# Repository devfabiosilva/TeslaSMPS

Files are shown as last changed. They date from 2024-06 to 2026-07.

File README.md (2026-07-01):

# TeslaSMPS

DIY: High Voltage Range Switching Mode Power Supply for Embedded / Solar and industrial systems

## 2026 KiCad Design Contest

Sponsored by PCB Way. See details [here](https://www.pcbway.com/project/shareproject/TeslaSMPS_Simple_3_Transistor_Ultra_Wide_Range_100V_820V_AC_142V_1160V_DC_c3cf9745.html)

<p align="center">
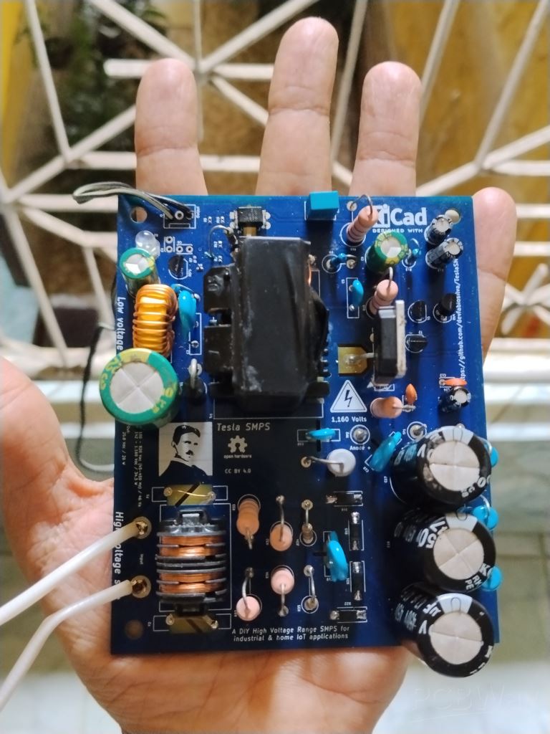
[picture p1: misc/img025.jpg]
  
</p>

<p align="center">
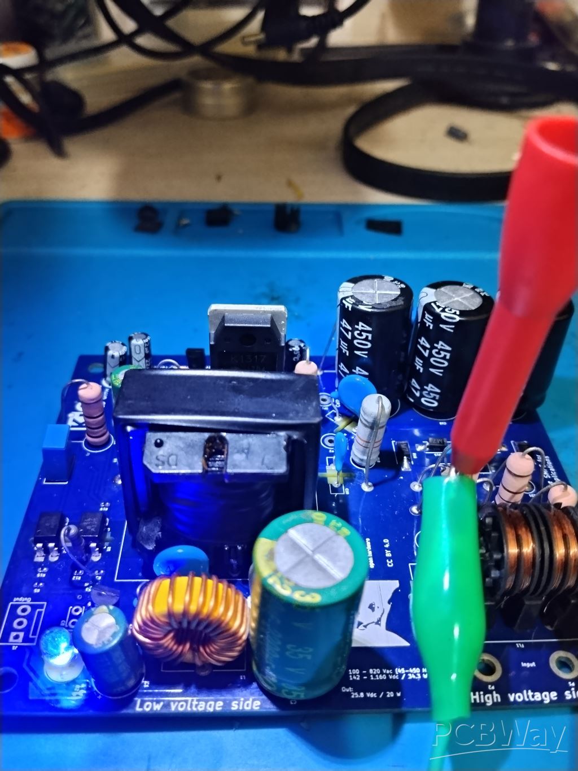
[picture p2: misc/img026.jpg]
  
</p>

### Old handmade version 2015

<p align="center">
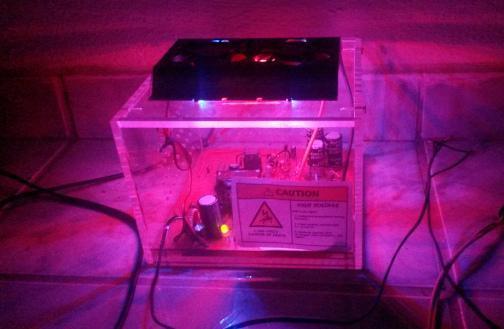
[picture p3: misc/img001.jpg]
  
</p>

## Brief description

This is a DIY WVR-SMPS (Wide Voltage Range Switching Mode Power Supply) or simply Tesla SMPS is a wide range and high voltage input for low power embedded systems. This device allows input voltage as low as 100 VAC and as high as 820 VAC in wide frequency range (45 − 450 Hz) or even in DC voltage as low as 142 VDC and as high as 1,160 VDC using only 3 transistors

[State of the art](https://github.com/devfabiosilva/TeslaSMPS/blob/master/01-concept/StateOfTheArt.pdf)

## Basic Block diagram

<p align="center">
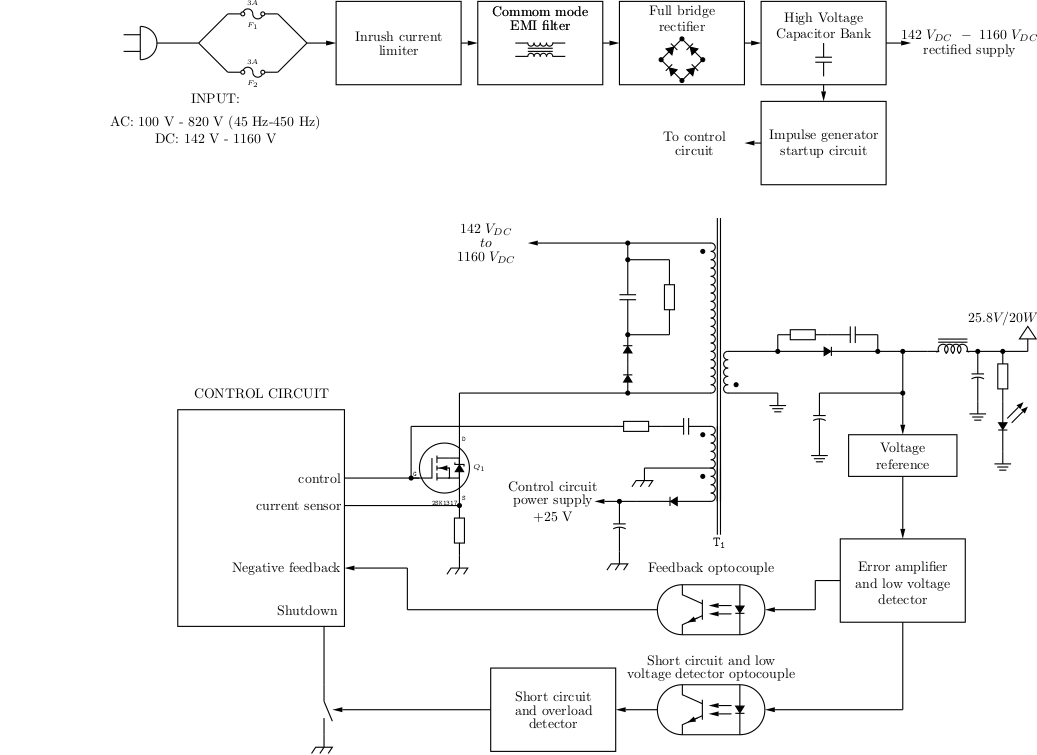
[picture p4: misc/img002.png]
  
</p>

## PCB Version

<p align="center">
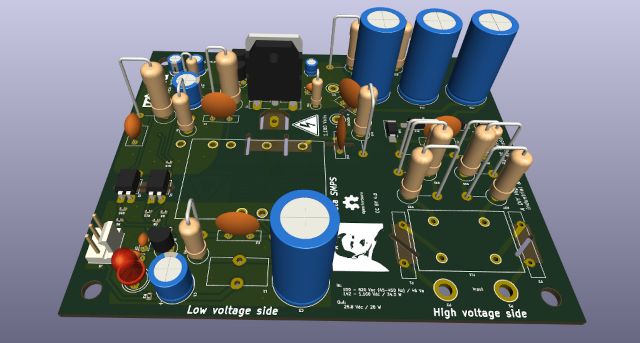
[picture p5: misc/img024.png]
  
</p>

<p align="center">
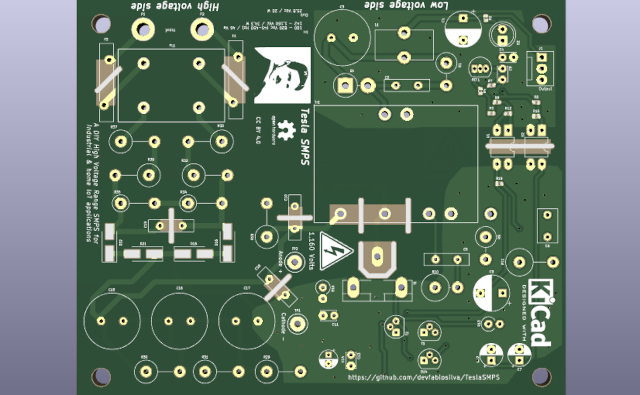
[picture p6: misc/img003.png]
  
</p>

You can find PCB version in:

- [Gerber files](https://github.com/devfabiosilva/TeslaSMPS/tree/master/02-schematic_and_gerber_files/gerber)

- [Source code](https://github.com/devfabiosilva/TeslaSMPS/tree/master/03-smd-project)

- [Schematic](https://github.com/devfabiosilva/TeslaSMPS/blob/master/02-schematic_and_gerber_files/2-schematic.pdf)

## Specifications

### Input Voltage:

AC 100 ~ 820 Volts (45 - 450 Hz)

DC 142 ~ 1,160 Volts

### Output Voltage:

DC 25.8 Volts (Insulated)

### Input Power

AC: 46 Va

DC: 34.3 W

### Eficiency

0.78 @ 180 VDC / 127 VAC

0.70 @ 500 VDC / 350 VAC

0.65 @ 1,160 VDC / 820 VAC

### THD
0.75

### Insulation

3,600 Volts

### Inrush current

42.6 Ampères @ 1,160 Volts

### (I^2)s Value

0.38 A^2-seconds

### Primary coil value

1.1 mH

### Primary coil peak current

933 mA

## Features

- Supply for low power Embedded or Solar Systems (max. power 20W)
- Safe high insulation for output voltage (max. 3,600V)
- Limited inrush current 42.6 A @ 1,160 Volts DC (0.38 A^2.s)
- High frequency range in AC operation (45 − 450Hz)
- AC/DC operation
- Static short circuit/overload protection
- Under voltage protection
- Low cost components (only 3 active elements!)
- Startup circuit
- Limited ID (current drain) monitor
- Secondary side grounded for security

## BEFORE YOU BEGIN:

### Remember: SAFETY FIRST

<p align="center">
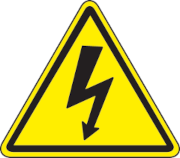
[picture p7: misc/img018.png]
  
</p>

### :skull::skull::skull: DANGER :skull::skull::skull:

This power supply works with very high voltage input. Care MUST be taken to avoid any personal injuries or death

- When power on high voltage, keep clear from input voltage cable.

- For input voltages above 300 Vac/Vdc negative output MUST be grounded with 10 Ohms impedance or less

- Keep in mind that this circuit stores high voltage even when power cord is off. If you want to repair or clear this SMPS wait at least 1 minute after remove power supply cord. Check test points TP1 (Cathode) and TP2 (Anode) pins with Voltimeter in scale 1,000 Vdc after touch or repair this circuit.

- This device has security circuit for under voltage, short circuit and overload. When one of these events occurs, this SMPS will stop working and we need to disconnect power cord, remove the problem and then wait 30 seconds to turn on power cord again. NOTICE: NEVER touch or open this circuit if one of these events occurs EVEN if you disconnected this device from power cord.

<p align="center">
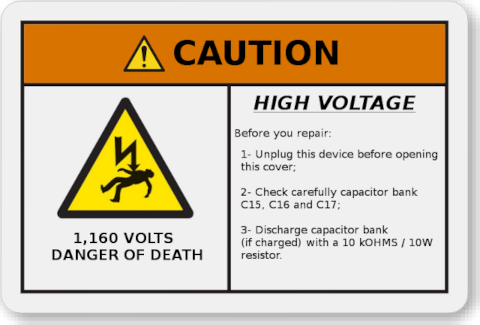
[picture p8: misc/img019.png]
  
</p>

## Building the transformer using recycled materials

You will need to rewind the transformer following these steps

## Step 1

- Find an old ATX power PCB

<p align="center">
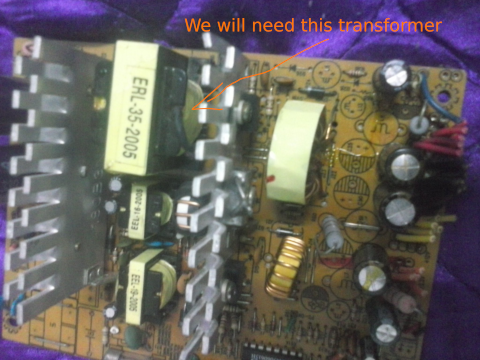
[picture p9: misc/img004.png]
  
</p>

<p align="center">
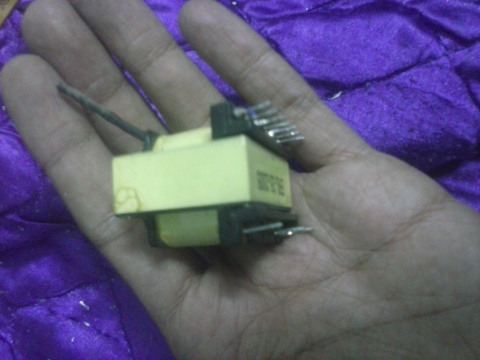
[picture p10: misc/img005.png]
  
</p>

## Step 2

- Disassemble the transformer core

<p align="center">
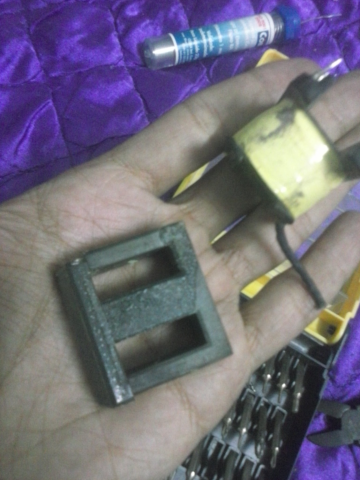
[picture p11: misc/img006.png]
  
</p>

<p align="center">
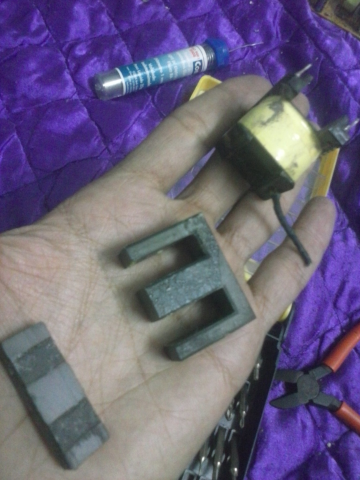
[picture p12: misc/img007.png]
  
</p>

You can use a EI or EE type ferrite core

[reference 1](https://en.wikipedia.org/wiki/Ferrite_core)

[reference 2](https://www.mag-inc.com/Products/Ferrite-Cores/Ferrite-Shapes/Learn-More-about-Ferrite-Shapes)

## Step 3

- Take the spool out of the core

<p align="center">
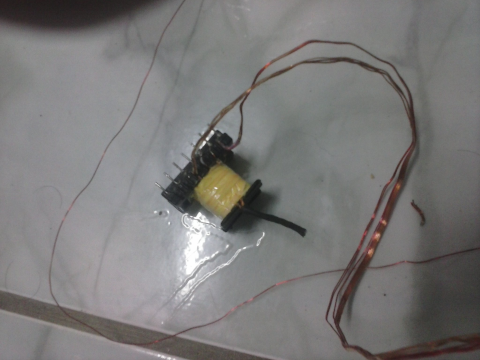
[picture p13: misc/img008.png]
  
</p>

<p align="center">
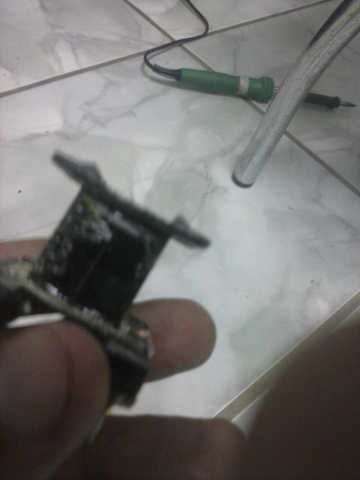
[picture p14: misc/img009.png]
  
</p>

## Step 4

- Rewind the transformer spool

<p align="center">
  
</p>

<p align="center">
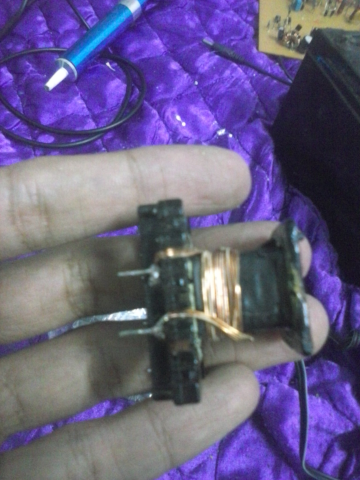
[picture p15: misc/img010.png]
  
</p>

<p align="center">
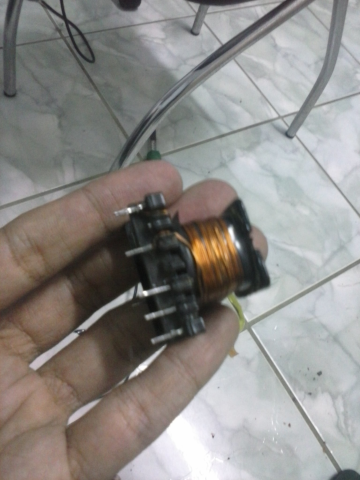
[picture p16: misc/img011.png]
  
</p>

- Rewinding turns:

<p align="center">
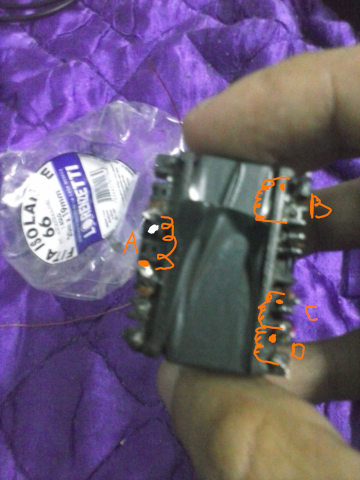
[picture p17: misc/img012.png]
  
</p>

- **A** - 4 turns (Secondary coil) (5 x 0.1 mm diameter *)

- **B** - 30 turns (Primary coil) (3 x 0.05 mm diameter *)

- **C** - 5 turns (Positive feedback coil) (0.1 mm diameter)

- **D** - 4 turns (Control circuit supply) (0.1 mm diameter)

_* Primary and secondary coil [skin effect](https://en.wikipedia.org/wiki/Skin_effect). Just interlace 3 x 0.05 mm copper wires and rewind the primary transformer spool and 5 x 0.1 mm copper wires in secondary coil_

See example below:

<p align="center">
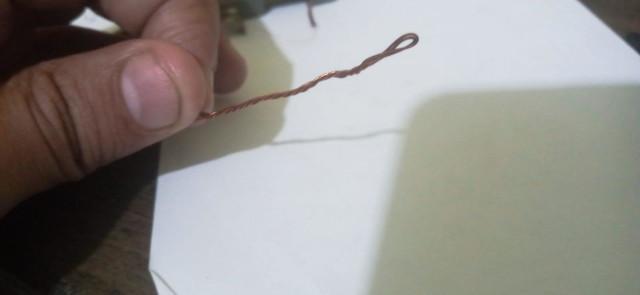
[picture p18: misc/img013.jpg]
  
</p>

_4 x 0.1mm interlaced wire_

## LAYERS AND INSULATORS

### INSULATION (WARNING !!!)

It is EXTREMELY IMPORTANT to insulate high voltage from secundary side. To do this you will need 6 layers of insulating tape to insulate 3.6 kV. Thus:

Transformer spool cross section example:

<p align="center">
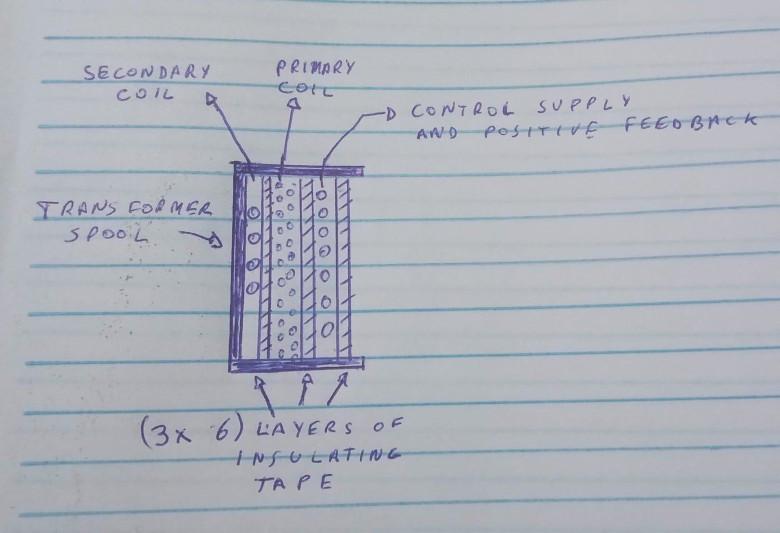
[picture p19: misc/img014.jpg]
  
</p>

Primary coil winding

<p align="center">
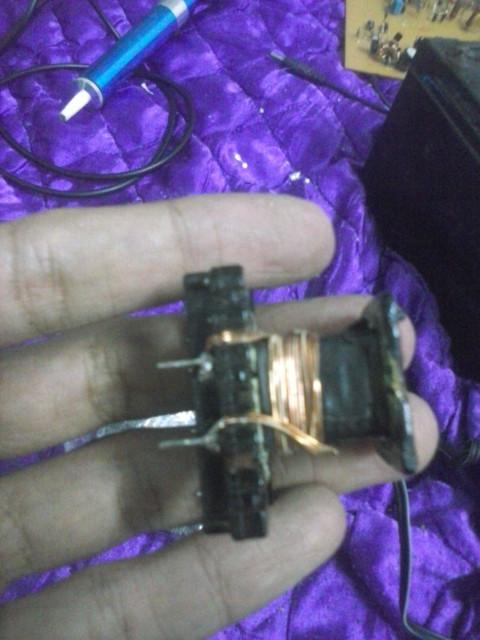
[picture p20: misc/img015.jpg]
  
</p>

_Control circuit supply_ and _control circuit supply_

<p align="center">
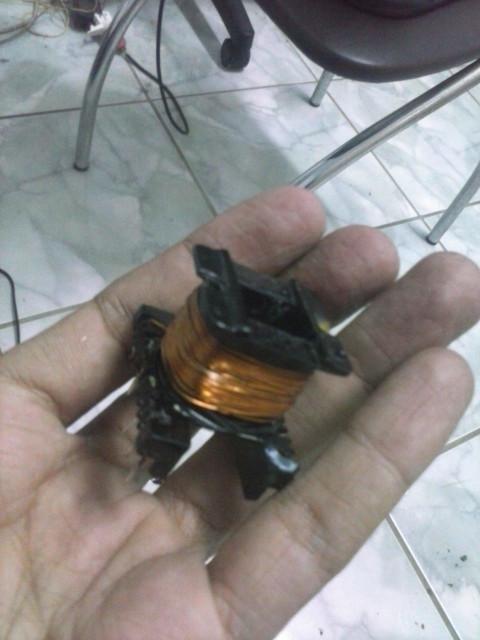
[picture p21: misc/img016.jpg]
  
</p>

Finishing insulation

<p align="center">
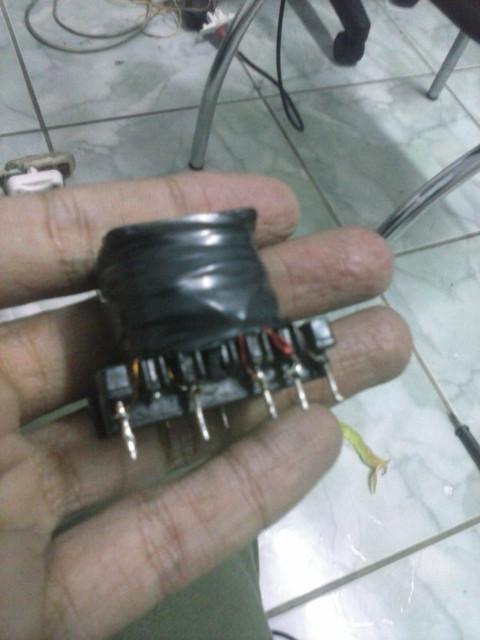
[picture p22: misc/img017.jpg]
  
</p>

### Creating the core gap:

[Flyback topology](https://www.coilcraft.com/en-us/edu/series/a-guide-to-flyback-transformers/) needs a [core gap](https://www.e-magnetica.pl/doku.php/air_gap) due to high peek flux to avoid saturation of the [ferrite coil](https://resources.pcb.cadence.com/blog/2022-what-is-a-ferrite-core)

So we need to create one _approx. 120um_ core gap using a non magnetic material. E.g.: a piece of paper

Take a A4 paper
<p align="center">
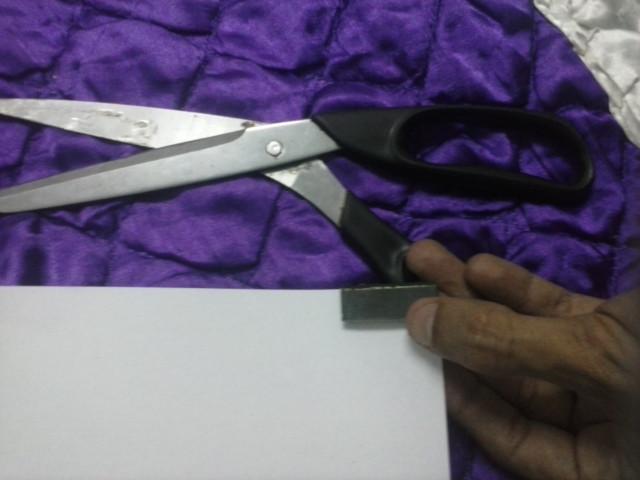
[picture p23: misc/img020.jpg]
  
</p>

Cut a piece of paper
<p align="center">
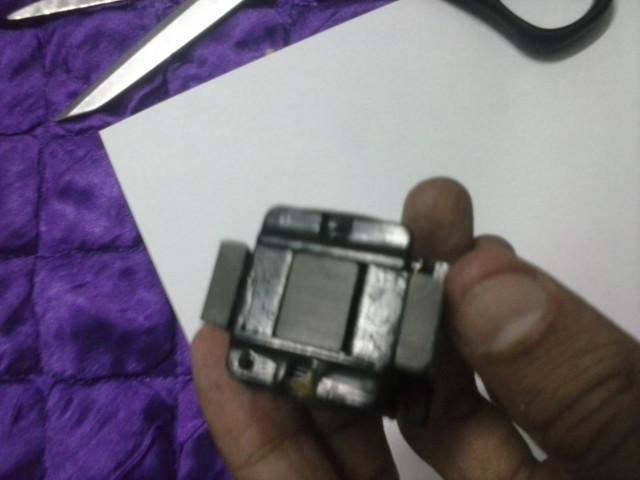
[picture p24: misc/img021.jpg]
  
</p>

Fix the piece of paper in transforme core
<p align="center">
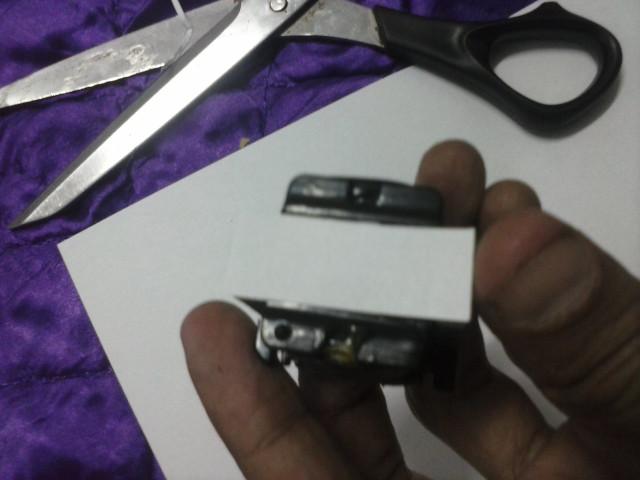
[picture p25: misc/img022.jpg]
  
</p>

Close the transformer core
<p align="center">
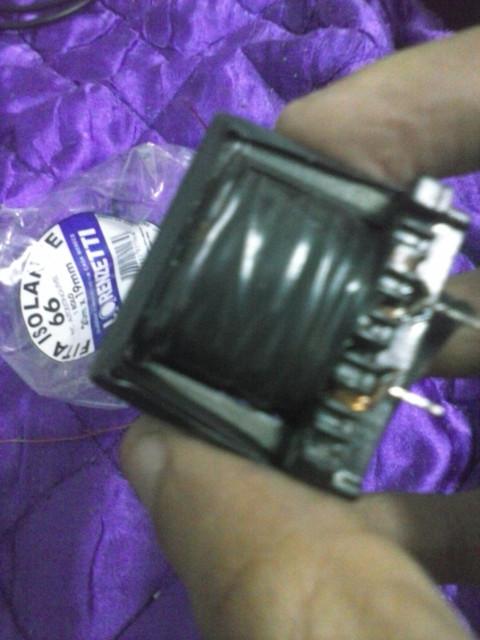
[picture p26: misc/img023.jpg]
  
</p>

Finally your transformer is ready to work in your Tesla SMPS

## Contact

Feel free to contact me at [fabioegel@gmail.com](mailto:fabioegel@gmail.com)

## Sponsors

This project is sponsored by [PCBWay](https://www.pcbway.com/)

## References

- [AN4148 Audible Noise Reduction Techniques for FPS Applications](https://www.onsemi.com/download/application-notes/pdf/an-4148.pdf)
- [High Voltage Printed Circuit Design & Manufactoring Notebook](https://www.magazines007.com/pdf/High-Voltage-PCDesign.pdf)
- [EEVblog #678 - What is a PCB Spark Gap?](https://www.youtube.com/watch?v=vfP_65gSSBU)

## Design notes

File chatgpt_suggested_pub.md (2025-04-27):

# TeslaSMPS – Simple High Voltage Switched-Mode Power Supply

**TeslaSMPS** is an extremely compact and functional flyback-based switched-mode power supply capable of operating with input voltages ranging from **140V ~ 1160V DC** or **100V ~ 820V AC**. Designed for simplicity, robustness, and reliability, it uses only **three active transistors** to deliver stable performance even under harsh conditions.

This project has been running for nearly 10 years with excellent results and now features an SMD version with a PCB designed in **KiCad**.

## ⚡ Main Features

- **Topology:** Self-oscillating Flyback
- **Active components:** Only 3 transistors
- **Input Voltage (AC):** 100V ~ 820V
- **Input Voltage (DC):** 140V ~ 1160V
- **Frequency:** Self-oscillating, depends on load and transformer
- **Short-circuit protection:** Yes, via optocoupler and RC sensing circuit
- **Isolation:** Ferrite transformer with custom winding

## 🧪 Operation and Protections

The circuit is based on natural oscillation initiated through feedback from the primary. The oscillation starts via a positive supply (through a high-value resistor) that polarizes the main transistor.

In the event of an **output short-circuit**, the RC circuit coupled to the optocoupler detects the overcurrent and blocks oscillation, immediately stopping primary conduction — protecting both transformer and transistors.

## 📐 PCB Design

- **Tool used:** KiCad
- **Current version:** First version with **SMD components**
- **Available files:**
  - Schematic
  - PCB layout
  - Gerber files
  - Bill of materials (BOM)

📁 Location: `PCB_SMD/` folder in the repository

## 🔧 Possible Applications

- High voltage power supplies
- Ignition drivers for coils
- Educational projects with isolated flyback
- Compact and robust power sources

## 📦 Repository Structure

```
TeslaSMPS/
├── PCB_SMD/           # SMD PCB files
├── Proteção/          # Short-circuit protection circuit
├── Imagens/           # Prototype and test images
├── kicad_projeto/     # Full KiCad project
├── Gerber/            # Manufacturing-ready files
└── README.md          # This file
```

## 📸 Images and Results

The `Imagens/` folder contains real photos of the mounted circuit, operational tests, primary waveform analysis, and protection response.

## 📃 License

This project is open-source. Feel free to use, study, modify, and share with proper attribution.

---

🔗 Repository: [TeslaSMPS](https://github.com/devfabiosilva/TeslaSMPS)

---

# TeslaSMPS – Fonte Chaveada Simples de Alta Tensão

**TeslaSMPS** é uma fonte chaveada do tipo *Flyback* extremamente compacta e funcional, capaz de operar com tensões de entrada entre **140V ~ 1160V DC** ou **100V ~ 820V AC**. Projetada para ser simples, robusta e confiável, ela utiliza apenas **três transistores** ativos para entregar desempenho estável mesmo sob condições severas.

Este projeto está em operação há quase 10 anos com ótimo desempenho, e agora conta com uma versão SMD com placa de circuito impresso projetada no **KiCad**.

## ⚡ Características principais

- **Topologia:** Flyback autoss oscilante
- **Componentes ativos:** Apenas 3 transistores
- **Tensão de entrada (AC):** 100V ~ 820V
- **Tensão de entrada (DC):** 140V ~ 1160V
- **Frequência:** Autoss oscilante, depende da carga e do trafo
- **Proteção contra curto-circuito:** Sim, via optoacoplador com detecção por RC no primário
- **Isolação:** Transformador de ferrite com bobinamento customizado

## 🧪 Funcionamento e Proteções

O circuito é baseado em uma oscilação natural que ocorre graças à realimentação vinda do primário. A oscilação é iniciada a partir de uma alimentação positiva (via resistor de alto valor), que polariza o transistor principal.

Em caso de **curto-circuito na saída**, o circuito RC acoplado ao optoacoplador detecta a sobrecorrente e bloqueia a oscilação, interrompendo imediatamente a condução do primário — protegendo tanto o trafo quanto os transistores.

## 📐 Projeto da PCB

- **Ferramenta utilizada:** KiCad
- **Versão atual:** Primeira versão com componentes **SMD**
- **Arquivos disponíveis:**
  - Esquemático
  - Layout PCB
  - Arquivos Gerber
  - Lista de materiais

🗂️ Localização: Pasta `PCB_SMD/` no repositório

## 🔧 Aplicações possíveis

- Alimentação de dispositivos de alta tensão
- Drivers de ignição para bobinas
- Projetos educacionais com flyback isolado
- Fontes de alimentação compactas e robustas

## 📦 Estrutura do repositório

```
TeslaSMPS/
├── PCB_SMD/           # Arquivos da placa SMD
├── Proteção/          # Circuito de proteção contra curto
├── Imagens/           # Fotos do protótipo e testes
├── kicad_projeto/     # Projeto completo no KiCad
├── Gerber/            # Arquivos prontos para fabricação
└── README.md          # Este arquivo
```

## 📸 Imagens e resultados

A pasta `Imagens/` contém fotos reais do circuito montado, testes de operação, análise da forma de onda no primário e resposta da proteção.

## 📃 Licença

Este projeto é open-source. Sinta-se à vontade para usar, estudar, modificar e compartilhar com atribuição.

---

🔗 Repositório: [TeslaSMPS](https://github.com/devfabiosilva/TeslaSMPS)

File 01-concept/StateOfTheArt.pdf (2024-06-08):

Creative Commons
CC BY 4.0

# Wide Voltage Range Tesla SMPS

### da Silva, Fabio Pereira ´

1
*

Abstract

This WVR-SMPS (Wide Voltage Range Switching Mode Power Supply) or simply Tesla SMPS is a wide range and high voltage input for low power embedded systems. This device allows input voltage as low as 100 VAC and as high as 820 VAC in wide frequency range (45−450 Hz) or even in DC voltage as low as 142 VDC and as high as 1,160 VDC

This white paper will show a detailed description and functionality of this circuit. There are only three active elements provinding control, oscillation, positive and negative feedback, short-circuit protection, overload and under-voltage protection.
Keywords
High voltage — SMPS — Tesla SMPS — Wide Range Power Supply — Embedded Power Devices

1Self-taught Engineer
*Corresponding author e-mail: fabioegel@gmail.com

### Contents

| Introduction | 1
1 | Motivation | 1
2 | Methods and why 25.8 Volts? | 2
2.1 Calculating fmax and fmin switching frequency . . . 3
3 | Measurements and results | 4
4 | Removing audible noise | 5
5 | HV-SMPS Characteristics | 7
6 | Conclusions | 7
| About the author | 7

### Introduction

This device called Tesla SMPS is a wide input voltage range suitable for embedded devices, such as: Sensors, IoT, measurements, embedded control systems.

It’s simply based Flyback topology using only discrete components. In this paper I will show how to build and detailed description for this device that use three active elements only. With three active elements, it’s possible to supply any low power embedded device with wide voltage and frequency range and so you can use it at any industrial and home application devices

### 1. Motivation

I was thinking what could I do to build and design my 8bit Embedded System and any other IoT devices to work at widely universal automotive and home and industry standard voltage into a single system. So I decided to design by myself this device that I called Tesla SMPS using recycled materials

I worked about 3 (three weeks) to design this device and one and half years to improve and fix some problems. After all tests and improvements I’ve found these results below:

1. Supply for low power Embedded System (max. power 20W)
2. Safe high insulation for output voltage (max. 2,600V)
3. Limited inrush current 42.6 A @ 1,160Volts DC (0.38A

2
s)
4. High frequency range in AC operation (45−450Hz)
5. AC/DC operation
6. Static short circuit/overload protection
7. Under voltage protection
8. Low cost components (only 3 active elements!)
9. Startup circuit
10. Limited ID (current drain) monitor
11. Secondary side grounded for security

Wide Voltage Range Tesla SMPS — 2/8

### 2. Methods and why 25.8 Volts?

My first prototype was designed to drive a load with an output voltage of 5 Volts and drive a maximum load of 10 Watts, but I had found one problem.

Due to high current drop in diode and high peak current the efficiency was lower than 60% and the maximum power was 6 Watts only instead of desired 10 Watts.

Using 4 principles of Physics in this circuit I had found an equation to find a good output voltage for maximizing efficiency at full load.

To design the entire circuitry and find a better efficiency at full load the 4 basic principles used are:

1. Faraday′
s Law
2. Law o f Conservation o f Energy
3. Lenz′
s Law
4. Ampere `

′
s Law

Using all principles of Physics above I had designed and I had found a good efficiency for the entire cicuitry. Analysing Flyback topology in Figure 1.

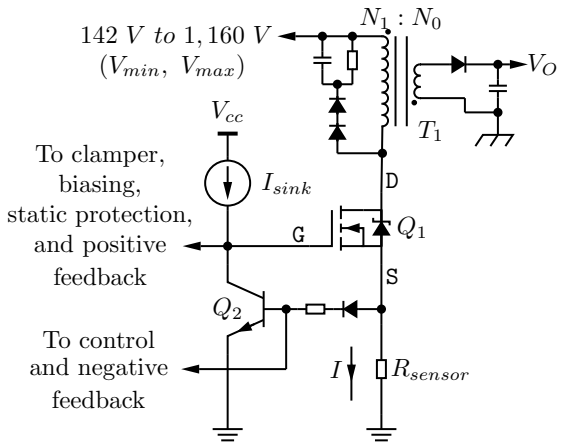
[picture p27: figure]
(Vmin, Vmax); To control and negative feedback; To clamper, biasing, static protection, and positive feedback; Vcc; Isink; Rsensor

Figure 1. Flyback topology in my Tesla SMPS

Let:

I ⇒ the maximum current peak

Vmin ⇒ the minimum voltage of the input circuit

Vmax ⇒ the maximum voltage of the input circuit

V1 | ⇒ input voltage
V0 | ⇒ desired output voltage
N0 | ⇒ number of turn in secondary coil
N1 | ⇒ number of turn in primary coil

Pmin ⇒ minimum output power

Pmax ⇒ maximum output power

T | ⇒ time period of switching
Ton | ⇒ time period on
To f f | ⇒ time period off
D | ⇒ duty cicle
L | ⇒ inductance of the primary coil
η | ⇒ estimated power efficiency

From Faraday′
| s Law¹ we get:
LI = V1Ton | (2.0.1)

From Law o f Conservation o f Energy² we get:

V1Ton = VrTo f f | (2.0.2)

Where Vr

is a reflected output voltage at primary coil when power transistor Q1 is turned off. Vr value is:

Vr = V0

N1
N0

(2.0.3)

Replacing Equation 2.0.3 into Equation 2.0.2 we get:

Ton

To f f

=

V0
V1

×

N1
N0

(2.0.4)

and

D =

1

1+

V1N0
V0N1

(2.0.5)

We know that the average power for a peak current I is:

P =

1
T

×

LI²

2

(2.0.6)

Replacing Equation 2.0.1 into Equation 2.0.6 we get:

P =

1
T

×

V1TonI
2

(2.0.7)

Wide Voltage Range Tesla SMPS — 3/8

We know that:

Ton = DT | (2.0.8)

Replacing Equation 2.0.8 into Equation 2.0.7 we get:

P =

V1I

2

1+

V1N0
V0N1
| (2.0.9)

We put an η (an estimated efficiency of 65%) to adjust 2.0.9 so, the final equation to find a better voltage and a good circuit synthesis is based in this formula based on 4 Physical Principles Laws:

P =

ηV1I

2

1+

V1N0
V0N1
| (2.0.10)

I made some interaction between coil ratio. Given values for 2.0.10 are:

I = 933 mA

Vmin = 142 Volts

Vmax = 1,160 Volts

V0 = 25.8 Volts

N0 = 4 Turns

N1 = 30 Turns

η = 0.65

Replacing into Equation 2.0.10

P(Vmin) = 0.65×142 Volts×933 mA

2

| 1+ 142 Volts×4 Turns

25.8 Volts×30 Turns = Pmin

So

Pmin ≈ 24.83 Watts

And

P(Vmax) = 0.65×1,160 Volts×933 mA

2

1+

1,160 Volts×4 Turns

25.8 Volts×30 Turns = Pmax

So

Pmax ≈ 50.28 Watts

Now we need to know about the maximum voltage in VD (voltage drain). The limitings factors for transistor are:

1. Switching frequency f
2. Maximum drain voltage VD
3. Maximum current drain ID

### 2.1 Calculating fmax and fmin switching frequency

To calculate frequency f let’s use Equation 2.0.1 and 2.0.8 then:

T =

LI
DV1

(2.1.1)

∴

f =

DV1
LI

(2.1.2)

f =

V1
1+

V1N0
V0N1
LI

(2.1.3)

With L = 1.1 mH and replacing all values in Equation 2.1.3 we get a maximum frequency at full load:

fmax =

1,160 Volts
1+

1,160 Volts×4 Turns
25.8 Volts×30 Turns
×1.1 mH ×933 mA

fmax ≈ 161.59 kHz

and

fmin =

142 Volts
1+

142 Volts×4 Turns
25.8 Volts×30 Turns
×1.1 mH ×933 mA

fmin ≈ 79.80 kHz

### 2.2 Calculating VDmax and VDmin

For calculating maximum voltage in transistor drain (VDS)it is necessary to know the voltage in rectified rail (VDC bus) and the reflected voltage of the output voltage (Vr) and (V0).We know that:

VDS = Vr +VDC | (2.2.1)

where:

VDS = V0

N1
N0
+VDC | (2.2.2)

Replacing Equation 2.2.2 with given values we get:

VDSmax = 25.8 Volts×

30 Turns
4 Turns

+1,160 Volts

Wide Voltage Range Tesla SMPS — 4/8

VDSmax = 1,353.50 Volts

and

VDSmin = 25.8 Volts×

30 Turns
4 Turns

+142 Volts

VDSmin = 335.50 Volts

### 2.3 Choosing the transistor

I had found a good transistor 2SK1317 from Renesas website¹ for this application.

In the Table 1 below we can see some characteristics from Renesas datasheet.

Table 1. 2SK1317 Main Characteristics (max. ratings)

| Value | Units
VDS | 1,500 | V
ID | 2.5 | A
Frequency | > 200 | kHz

### 2.4 Analyzing Equation 2.0.10

Analyzing Equation 2.0.10 we can see advantages such as:

1. Increase output power at same range of input voltage
2. Decrease mean current in schottky diode and increase eficiency of my Testa SMPS
3. Easy regulation with higher power
4. Post regulation. Using step-down or step-up circuit regulators this voltage can be easily regulated as low as 3.3 V or 5 V. Standard voltages for microcrontrollers such as Arduino, Raspberry Pi, or as high as 50 V for others purposes.

### 3. Measurements and results

As you can see the results shown in Figure 2 is not acceptable.

After improvements and new re-design of my Tesla SMPS using Equation 2.0.10, new good results and characteristics are shown in Table 2.

1Renesas 2SK1317 datasheet (https://www.renesas.com/us/en/doc/products/transistor/003/rej03g0929_2sk1317ds.pdf)

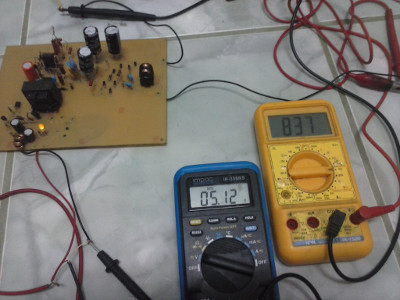
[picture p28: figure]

Figure 2. My first prototype testing before improvements:

Input voltage : 837 VAC @ 60 Hz Out put voltage : 5.12 VDC/6 W

We can also see the measurements in my osciloscope in Figures 3 and 4 below after re-design and improve my Tesla SMPS:

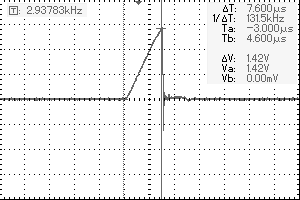
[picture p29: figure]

Figure 3. Peak current I = 946 mA with Rsensor = 1.5 Ω

(500 mV/DIV)
(5 µs/DIV)

Now, with only 3 (three) transistors we can control current, positive and negative feedback, overload and short circuit in primary coil. No integrated circuit is needed to do all this operation. Main focus here is to prove and build with only active and passive elements a very high range input SMPS with recycled materials. Good and acceptable results were found in my project.
Analyzing Figure 4 we can see the control circuit waveform at power transistor gate (VGS). It’s quite different as we expected and you expected a square wave but it’s waveform makes sense. Let’s analyze it step by step.

First of all let’s see Figure 1.

Wide Voltage Range Tesla SMPS — 5/8

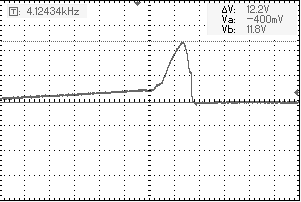
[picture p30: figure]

Figure 4. Peak VGS = 12.2 V

(5 V/DIV)
(5 µs/DIV)

Now dividing information in Figure 4 into 3 parts (A,B and C) and showing in Figure 5 below:

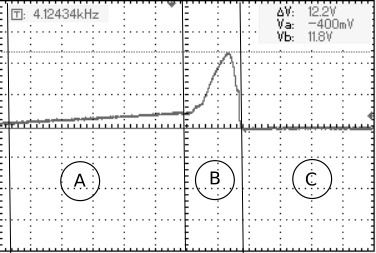
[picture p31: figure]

Figure 5. Peak VGS = 12.2 V

(5 V/DIV)
(5 µs/DIV)

Analyzing A region: In region A (Figure 5), power transistor in Q1 (Figure 1) and transistor Q2 is o f f . Q2 transistor is o f f because there are no current in sensor drain Isensor and output value VO is below threshold voltage reference (negative feedback disabled). Q1 transistor is o f f because positive feedback is disable by voltage applied in the gate is below (Vth ≈ 4 V), where, Vth is threshold voltage of the power transistor Q1. Static protection is enabled only if some atypical behavior (malfunction) occurs. Only current source Isink is driving the gate of Q1. Region A is also known as dead- time, where negative feedback is off and there are no magnetic energy into the transformer core. Decreasing dead-time, we can increase performance increasing output power. Adjusting Isink we could improve swicthing for this application. We can also estimate capacitance including gate and circuitry capacitance using only result obtained from measurements in Figure 4.

Isink = C

dVGS
dt

(3.0.1)

Isink = C

∆VGS
∆t

(3.0.2)

Given values:

Isink ≈ 4.54 mA

∆VGS ≈ 4 V

∆t ≈ 30 µs

∴

C ≈ 34 nF

WhereC is the total capacitance of gate and control circuit.

Analyzing B region: When voltage in VGS reaches threshold voltage (Vth), power transistor begins to inject current in primary coil of the transformer T1. Positive feedback is active at this moment and it forces voltage slope to get higher until it reaches a 12V maximum voltage. Clamper guarantees that the maximum voltage in VGS not exceed 12 V. At this time ID (primary coil current) is linear as shown in Figure 3

Analyzing C region: When voltage through Rsensor in Figure 1 exceeds ≈ 1.4 Volts transistor Q2 turns on forcing voltage gate VGS close to 0 Volt. Control circuit and negative feedback force Q2 base being polarized until all magnetic energy stored in transformer core T1 beeing transfered to secondary circuitry. When all magnetic energy is trasnfered and/or negative feedback is open all process begins a new cycle.

### 4. Removing audible noise

Burst frequency and a high flux peak are the main issue for audible noises.

I had found a good article 2
explaining a good method to reduce this problem. To solve this problem, I had put a RC low pass-filter in voltage reference in secondary side. Decreasing burst switching frequency and its amplitude it is a good way to decrease or even eliminate audio noise when no load is present in the output voltage.

2Audible Noise Reduction Techniques for FPS Applications (https://www.onsemi.com/download/application-notes/pdf/an-4148.pdf)

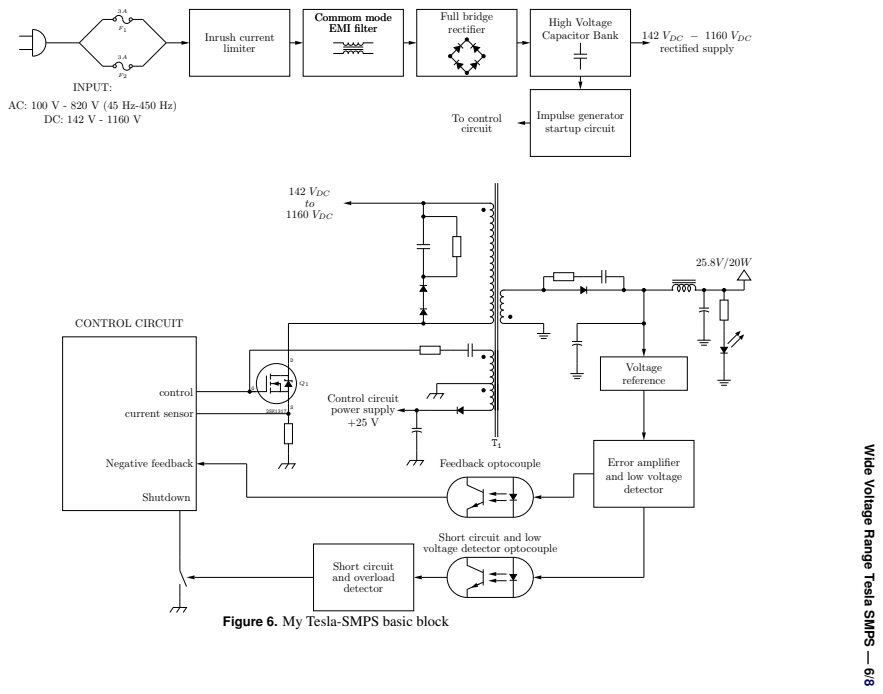
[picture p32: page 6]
Inrush current limiter; Commom mode EMI filter; Full bridge rectifier; High Voltage; Capacitor Bank; VDC; VDC rectified supply; Impulse generator startup circuit; To control circuit; Voltage reference; Feedback optocouple; Control circuit power supply +25 V; Short circuit and overload detector; VDC to 1160; control; current sensor; Shutdown; CONTROL CIRCUIT; Negative feedback; INPUT:

Wide Voltage Range Tesla SMPS — 6/

Error amplifier
and low voltage
detector

Short circuit and low
voltage detector optocouple

Figure 6. My Tesla-SMPS basic block

Wide Voltage Range Tesla SMPS — 7/8

### 5. HV-SMPS Characteristics

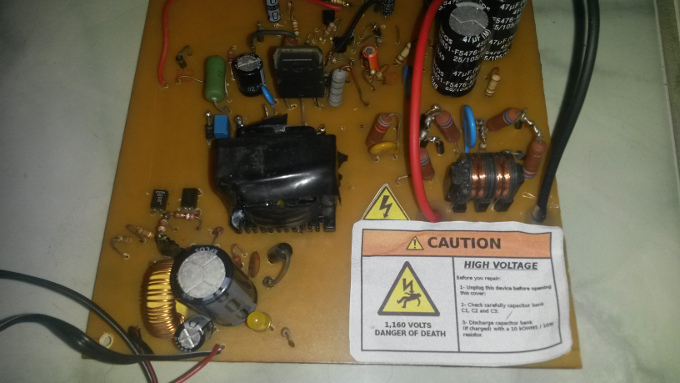
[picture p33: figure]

Figure 7. My sencond and final improved prototype

Table 2. Tesla-SMPS Main Characteristics (max. ratings)

Input Voltage: | AC 100 ∼ 820 Volts
| DC 142 ∼ 1,160 Volts
Output Voltage: | DC 25.8 Volts (Insulated)
Input power (max): | 34.3 W/46 Va
Output power (max): | 20 W
Frequency: | 0 Hz or 45 Hz ∼ 450 Hz
Eficiency: (stimated) | 0.78 @ 180 VDC/127 VAC
| 0.70 @ 500 VDC/350 VAC
| 0.65 @ 1,160 VDC/820 VAC

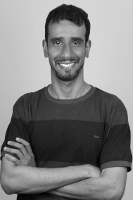
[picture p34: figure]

THD: | 0.75
Insulation: | 2,600 VRMS
Inrush current: | 42.6 A @ 1,160 VDC

I

2
t value @ 1,160 VDC: | 0.38 A
| 2
| s
Primary coil value: | 1.1 mH
Primary coil peak current: | 933 mA

### 6. Conclusions

I’ve made some test with my first automation prototype and other embedded computer. This was quite versatile. So we are able to supply any low power embedded devices to a wide voltage range (industrial/home application). Some photos and real time measurements.

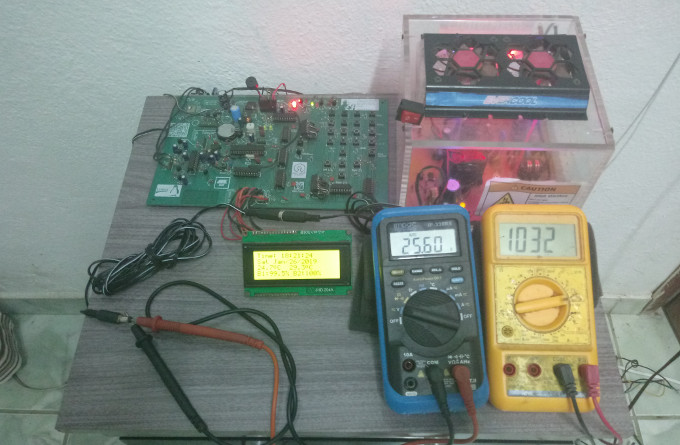
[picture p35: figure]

Figure 8. My embedded working @ 1032Vdc to 25.60 Vdc

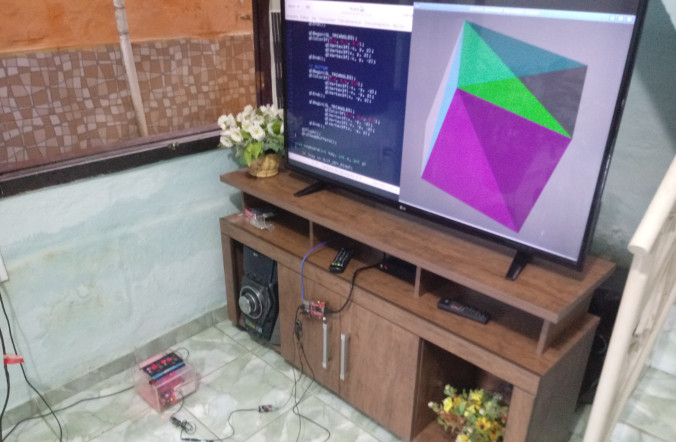
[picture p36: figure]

Figure 9. Linux embedded using my Tesla SMPS

### About the author

Fabio Pereira da Silva ´ | (Rio
de Janeiro, Brazil 1981)

is a self-taught Engineer, Hobbyist, Linux and Crypto Lover

I | believe | voluntarianism
and sharing acknowledgements to build better world.
For | contact, | please
fabioegel@gmail.com

Wide Voltage Range Tesla SMPS — 8/8

Thanks to
http://www.LaTeXTemplates.com for this beautiful LATEX white paper template.

Commercial and licenses

This document is under license of Creative Commons 4.0. (https://creativecommons.org/licenses/by/4.0/) You are free to use and share all contents here.

Any question e-mail me at: fabioegel@gmail.com

More details and DIY PCB project are available at my github repository: https://github.com/devfabiosilva/TeslaSMPS/

Donations
Please, consider donate any little amount of money. You can donate with Bitcoin, Litecoin, Nano or even Dogecoin.

Bitcoin (BTC)

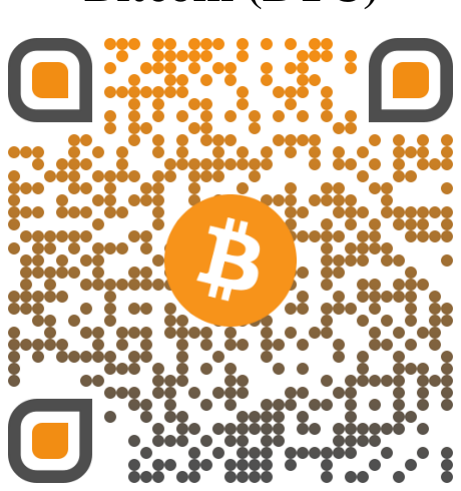
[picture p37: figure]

1JDckpLRJGhp46LTcjY1vsW19wurZ3L1d5

Nano (XRB)

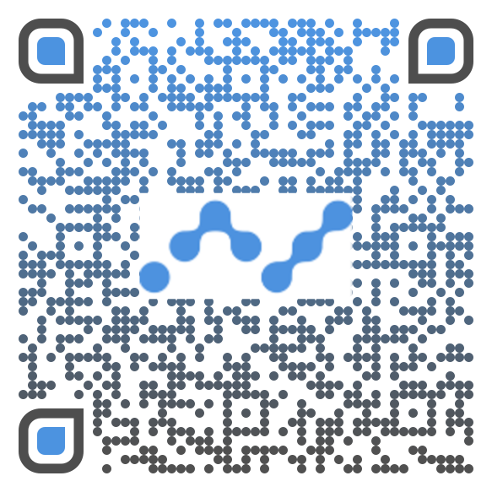
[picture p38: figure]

nano 1cb5fs7xmixqzpitfn9ouy4j1g3hjmdfudc1igt5xhwwps7qdku5htqxmznb

Litecoin (LTC)

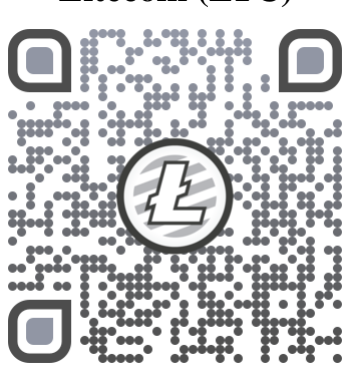
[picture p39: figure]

LRjEiKadFzPCoGorWvSVUnWPsFyPZGt97f

Dogecoin (DOGE)

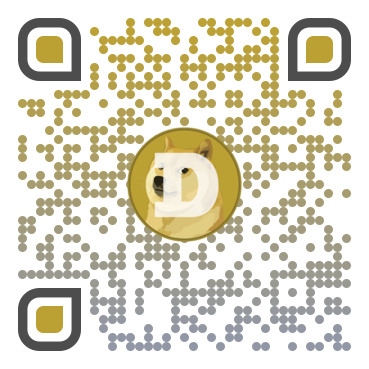
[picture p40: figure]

DRrWWMdwY6AN8rdz7zH2cp3qaK8vSgDTau

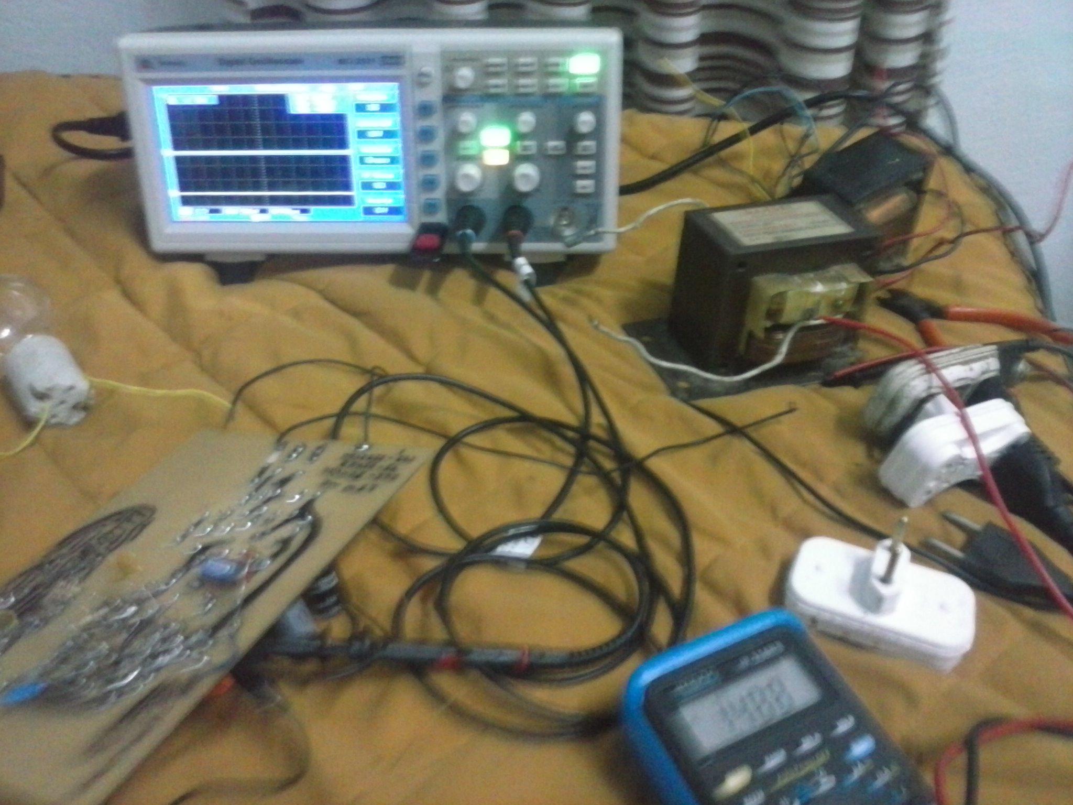
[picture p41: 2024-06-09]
04-hand-made-prototype/01-Begin/CAM01236.jpg

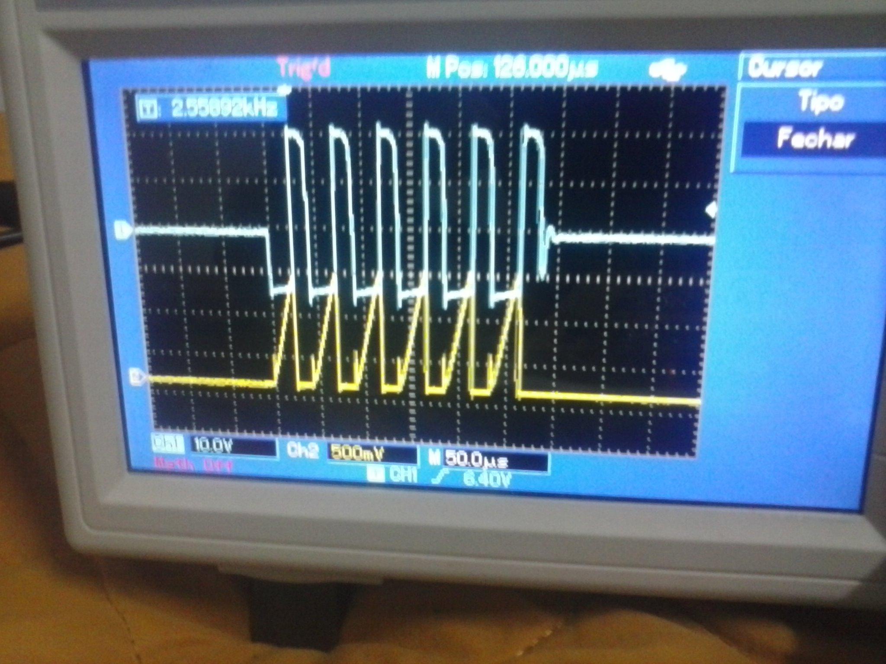
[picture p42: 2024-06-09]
04-hand-made-prototype/01-Begin/CAM01207.jpg

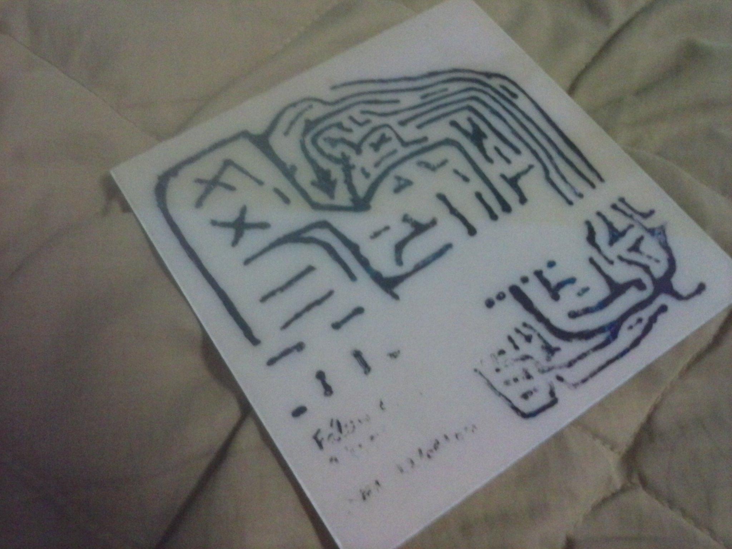
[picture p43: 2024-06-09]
04-hand-made-prototype/01-Begin/CAM01348.jpg

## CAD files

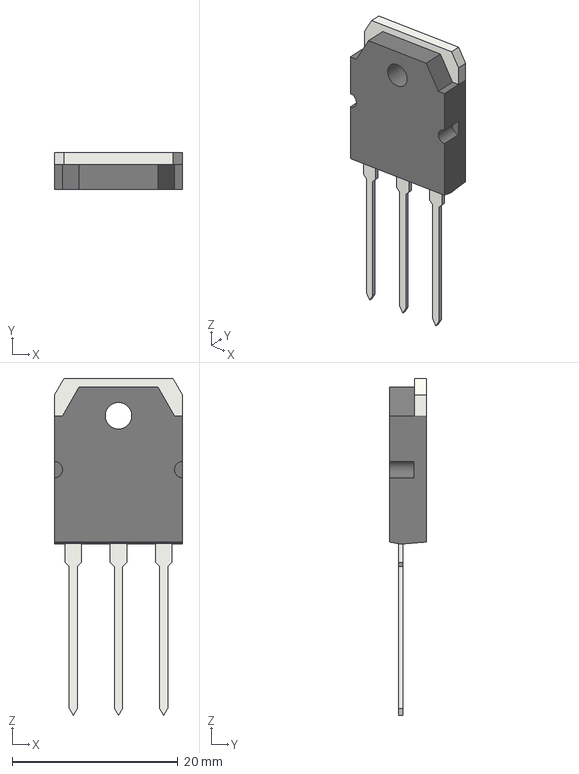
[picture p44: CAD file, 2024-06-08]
03-smd-project/fmodules/TO-3P-3_Vertical.step
15.5 x 4.51 x 40.7 mm

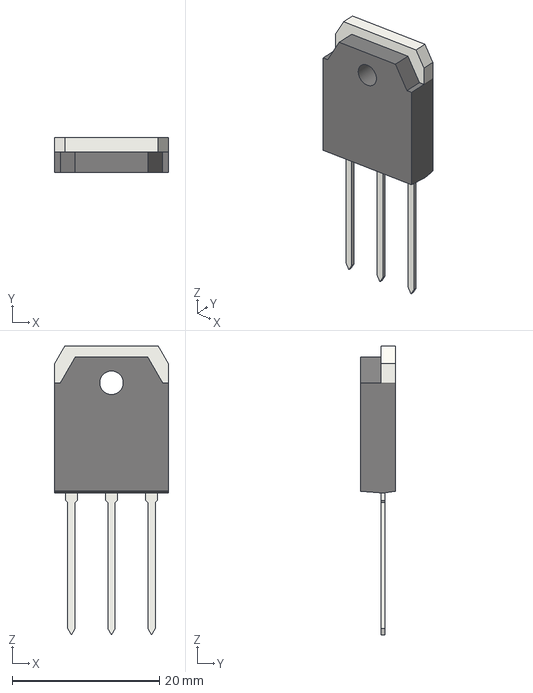
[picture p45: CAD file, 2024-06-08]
03-smd-project/fmodules/TO-3PB-3_Vertical.step
15.5 x 4.81 x 39.3 mm

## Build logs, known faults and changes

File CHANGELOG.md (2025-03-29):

# Changelog
Tesla SMPS Changelogs:

## [1.1] (03/29/2025) (RELEASE CANDIDATE)

- Fix SMD resistor type due to max. power dissipation R22 = 1K 0402 to 2010 ✔️
- Chance capacitor footprint C3 to Capacitor_THT:CP_Radial_D16.0_P7.50mm ✔️
- Chance capacitor footprint C15, C16 and C17 to Capacitor_THT:CP_Radial_D16.0_P7.50mm ✔️
- Fix SMD resistor type due to max. power dissipation R2 = 2.2k 0402 to 0806 ✔️
- Fix SMD resistor type due to max. power dissipation R8 = 4.7k 0402 to 0806 ✔️
- Change Capacitors C15, C16 and C17 footprint to C_Radial_D16.0mm_H31.5mm_P7.50mm ✔️
- Change Resistor footprint R16 to Resistor_THT:R_Axial_DIN0614_L14.3mm_D5.7mm_P5.08mm_Vertical ✔️
- Chance capacitor footprint C3 to Capacitor_THT:C_Radial_D16.0mm_H25.0mm_P7.50mm ✔️
- Chance capacitor footprint C1 to Capacitor_THT:CP_Radial_D8.0mm_P3.50mm ✔️
- Chance capacitor footprint C9 to Capacitor_THT:CP_Radial_D8.0mm_P3.50mm ✔️

## [master] - current

[master]: https://github.com/devfabiosilva/TeslaSMPS/tree/master

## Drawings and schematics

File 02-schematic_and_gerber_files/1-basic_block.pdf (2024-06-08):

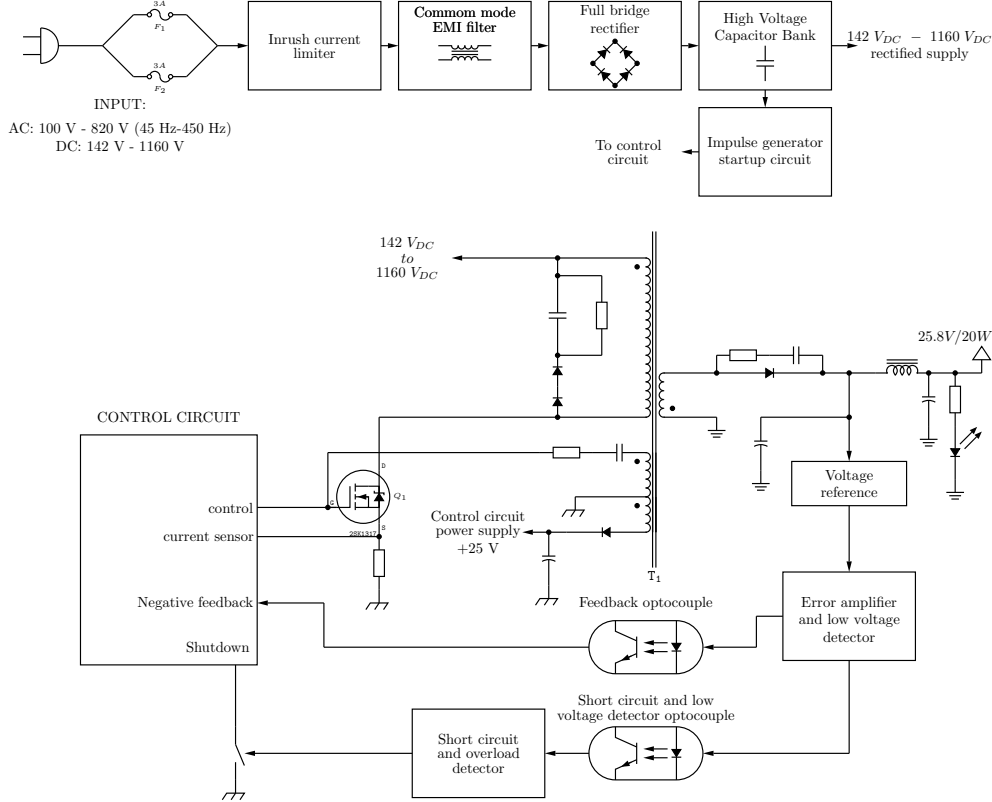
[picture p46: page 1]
Inrush current limiter; Commom mode EMI filter; Full bridge; rectifier; High Voltage; Capacitor Bank; 142 VDC; 1160 VDC; rectified supply; Impulse generator startup circuit; To control circuit; Voltage reference; Feedback optocouple; Control circuit power supply +25 V; Short circuit and overload detector; 142 VDC to 1160 VDC; control; current sensor; Shutdown; CONTROL CIRCUIT; Negative feedback; INPUT:

Error amplifier
and low voltage
detector

Short circuit and low
voltage detector optocouple

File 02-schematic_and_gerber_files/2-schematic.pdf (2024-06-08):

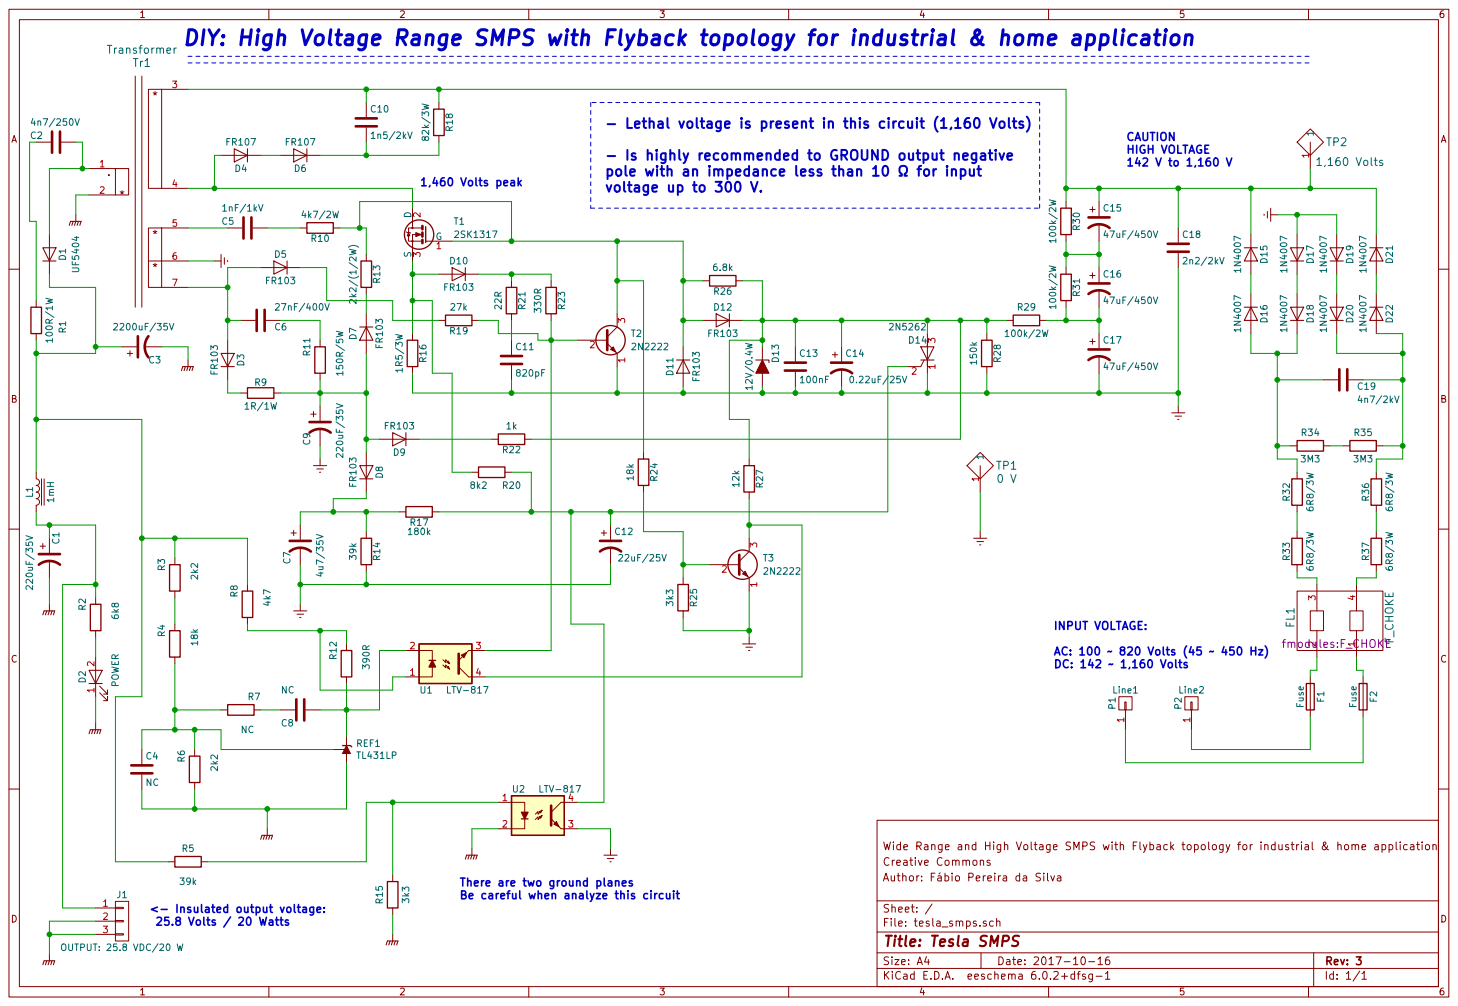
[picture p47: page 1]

DIY: High Voltage Range SMPS with Flyback topology for industrial & home application

- Lethal voltage is present in this circuit (1,160 Volts)

- Is highly recommended to GROUND output negative
voltage up to 300 V.

INPUT VOLTAGE: AC: 100 ~ 820 Volts (45 ~ 450 Hz)

File: tesla_smps.sch Sheet: / þÿAuthor: Fábio Pereira da Silva Creative Commons Wide Range and High Voltage SMPS with Flyback topology for industrial & home application

There are two ground planes
Be careful when analyze this circuit

Id: 1/1 Title: Tesla SMPS

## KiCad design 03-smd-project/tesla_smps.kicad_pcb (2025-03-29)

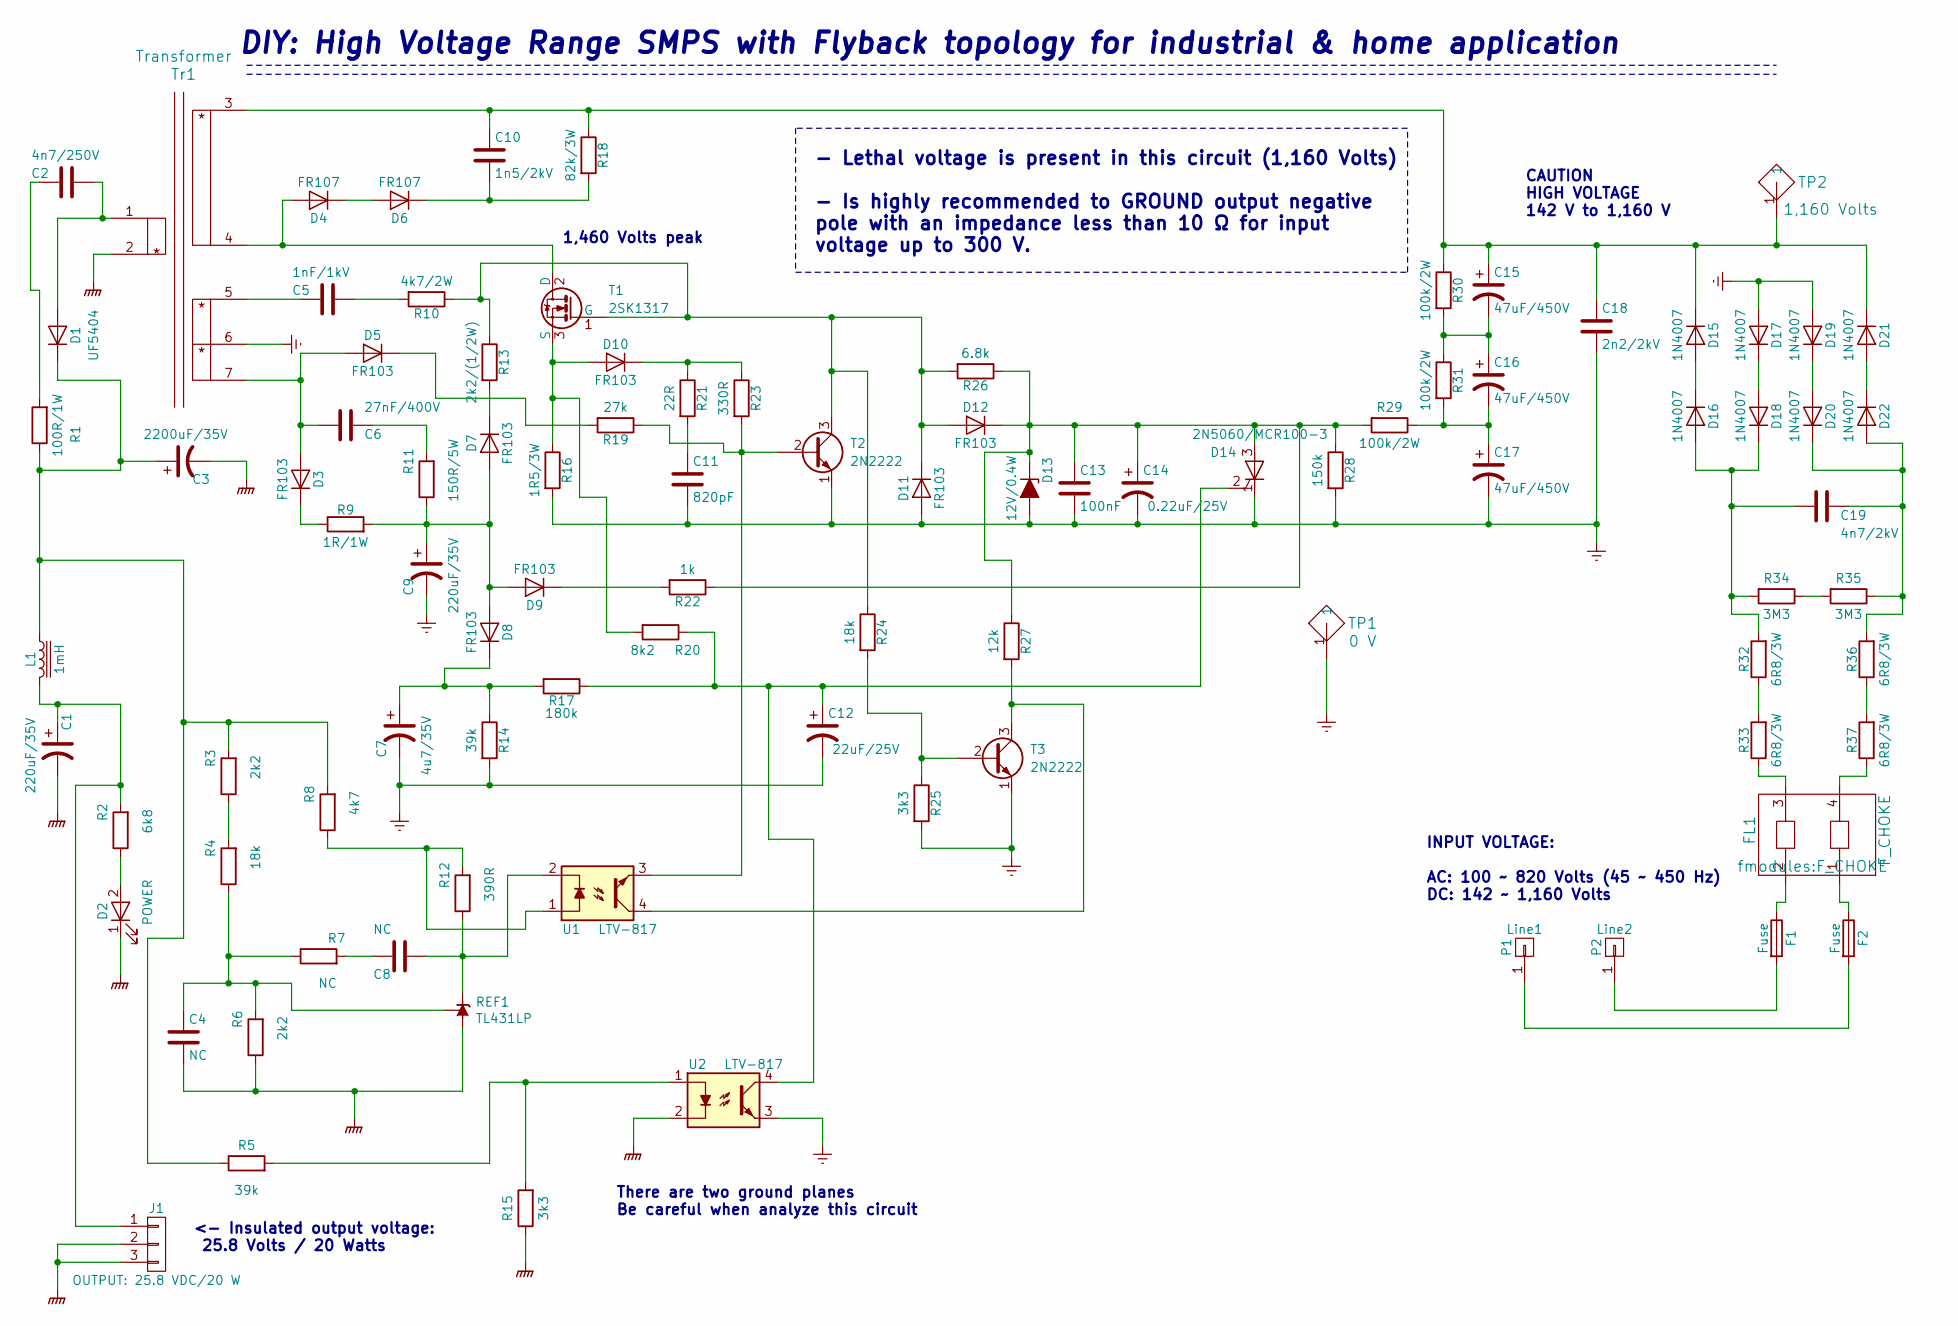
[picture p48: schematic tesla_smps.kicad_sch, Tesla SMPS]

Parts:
C1, C9: 220uF/35V; CP_Radial_D8.0mm_P3.50mm
C2: 4n7/250V; C_Disc_D10.0mm_W2.5mm_P5.00mm
C3: 2200uF/35V; CP_Radial_D16.0mm_P7.50mm
C4, C8: NC; C_Disc_D3.4mm_W2.1mm_P2.50mm
C5: 1nF/1kV; C_Disc_D10.0mm_W2.5mm_P5.00mm
C6: 27nF/400V; C_Disc_D7.5mm_W4.4mm_P5.00mm
C7: 4u7/35V; CP_Radial_D5.0mm_P2.50mm
C10: 1n5/2kV; C_Disc_D10.0mm_W2.5mm_P5.00mm
C11: 820pF; C_Disc_D3.4mm_W2.1mm_P2.50mm
C12: 22uF/25V; CP_Radial_D5.0mm_P2.50mm
C13: 100nF; C_Disc_D3.4mm_W2.1mm_P2.50mm
C14: 0.22uF/25V; CP_Radial_D4.0mm_P2.00mm
C15, C16, C17: 47uF/450V; CP_Radial_D16.0mm_P7.50mm
C18: 2n2/2kV; C_Disc_D7.5mm_W4.4mm_P5.00mm
C19: 4n7/2kV; C_Disc_D7.5mm_W4.4mm_P5.00mm
D1: UF5404; D_DO-201AD_P5.08mm_Vertical_AnodeUp
D2: POWER; LED_D5.0mm
D3, D5, D7, D8, D9, D10, D11, D12: FR103; D_SMA_Handsoldering
D4, D6: FR107; D_SMA_Handsoldering
D13: 12V/0.4W; D_SOD-323F
D14: 2N5060/MCR100-3; TO-92
D15, D16, D17, D18, D19, D20, D21, D22: 1N4007; D_SMA
F1, F2: Fuse; Fuse_Bourns_MF-RHT1000
FL1: F_CHOKE
J1: OUTPUT: 25.8 VDC/20 W; FanPinHeader_1x03_P2.54mm_Vertical
L1: 1mH; L_Toroid_Vertical_L13.0mm_W6.5mm_P5.60mm
P1: Line1; F_PIN
P2: Line2; F_PIN
R1: 100R/1W; R_Axial_DIN0414_L11.9mm_D4.5mm_P5.08mm_Vertical
R2: 6k8; R_0805_2012Metric
R3, R6: 2k2; R_0402_1005Metric
R4, R24: 18k; R_0402_1005Metric
R5, R14: 39k; R_0402_1005Metric
R7: NC; R_0402_1005Metric
R8: 4k7; R_0805_2012Metric
R9: 1R/1W; R_Axial_DIN0414_L11.9mm_D4.5mm_P5.08mm_Vertical
R10: 4k7/2W; R_Axial_DIN0617_L17.0mm_D6.0mm_P5.08mm_Vertical
R11: 150R/5W; R_Axial_DIN0617_L17.0mm_D6.0mm_P7.62mm_Vertical
R12: 390R; R_0402_1005Metric
R13: 2k2/(1/2W); R_Axial_DIN0309_L9.0mm_D3.2mm_P2.54mm_Vertical
R15, R25: 3k3; R_0402_1005Metric
R16: 1R5/3W; R_Axial_DIN0614_L14.3mm_D5.7mm_P5.08mm_Vertical
R17: 180k; R_0402_1005Metric
R18: 82k/3W; R_Axial_DIN0516_L15.5mm_D5.0mm_P7.62mm_Vertical
R19: 27k; R_0402_1005Metric
R20: 8k2; R_0402_1005Metric
R21: 22R; R_0402_1005Metric
R22: 1k; R_2010_5025Metric_Pad1.40x2.65mm_HandSolder
R23: 330R; R_0402_1005Metric
R26: 6.8k; R_0402_1005Metric
R27: 12k; R_0402_1005Metric
R28: 150k; R_0402_1005Metric
R29, R30, R31: 100k/2W; R_Axial_DIN0516_L15.5mm_D5.0mm_P7.62mm_Vertical
R32, R33, R36, R37: 6R8/3W; R_Axial_DIN0516_L15.5mm_D5.0mm_P7.62mm_Vertical
R34, R35: 3M3; R_Axial_DIN0411_L9.9mm_D3.6mm_P7.62mm_Vertical
REF1: TL431LP; TO-92_Inline
T1: 2SK1317; TO-3P-3_Vertical
T2, T3: 2N2222; TO-92
TP1: 0 V; 1pin
TP2: 1,160 Volts; 1pin
Tr1: Transformer; F_TR
U1, U2: LTV-817; DIP-4_W7.62mm_LongPads

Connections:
GNDPWR: C1.2, C3.2, C4.2, D2.1 (K), J1.2, J1.3, R6.1, R15.1, REF1.2 (A), Tr1.2, U2.2
GNDREF: C7.2, C9.2, C11.2, C12.2, C13.2, C14.2, C17.2, C18.2, D11.2 (A), D13.2 (A), D14.1 (K), D17.2 (A), D19.2 (A), R14.2, R16.2, R25.2, R28.2, T2.1 (E), T3.1 (E), TP1.1, Tr1.6, U2.3
unnamed: C1.1, J1.1, L1.2, R2.2
unnamed: C2.1, D1.2 (A), Tr1.1
unnamed: C2.2, R1.2
unnamed: C3.1, D1.1 (K), L1.1, R1.1, R3.2, R5.1, R8.2
unnamed: C4.1, R4.1, R6.2, R7.1, REF1.1 (REF)
unnamed: C5.1, R10.2
unnamed: C5.2, Tr1.5
unnamed: C6.1, R11.2
unnamed: C6.2, D3.2 (A), D5.2 (A), Tr1.7
unnamed: C7.1, D8.1 (K), R14.1, R17.2
unnamed: C8.1, R12.1, REF1.3 (K), U1.2
unnamed: C8.2, R7.2
unnamed: C9.1, D7.2 (A), D8.2 (A), D9.2 (A), R9.2, R11.1
unnamed: C10.1, C15.1, C18.1, D15.1 (K), D21.1 (K), R18.1, R30.1, TP2.1, Tr1.3
unnamed: C10.2, D6.1 (K), R18.2
unnamed: C11.1, R21.2
unnamed: C12.1, D14.2 (G), R17.1, R20.1, U2.4
unnamed: C13.1, C14.1, D12.1 (K), D13.1 (K), D14.3 (A), R22.1, R26.1, R27.1, R28.1, R29.2
unnamed: C15.2, C16.1, R30.2, R31.1
unnamed: C16.2, C17.1, R29.1, R31.2
unnamed: C19.1, D20.1 (K), D22.2 (A), R35.1, R36.2
unnamed: C19.2, D16.2 (A), D18.1 (K), R32.2, R34.2
unnamed: D2.2 (A), R2.1
unnamed: D3.1 (K), R9.1
unnamed: D4.1 (K), D6.2 (A)
unnamed: D4.2 (A), T1.2 (D), Tr1.4
unnamed: D5.1 (K), R19.2
unnamed: D7.1 (K), R13.2
unnamed: D9.1 (K), R22.2
unnamed: D10.1 (K), R21.1, R23.1
unnamed: D10.2 (A), R16.1, R20.2, T1.3 (S)
unnamed: D11.1 (K), D12.2 (A), R10.1, R13.1, R24.1, R26.2, T1.1 (G), T2.3 (C)
unnamed: D15.2 (A), D16.1 (K)
unnamed: D17.1 (K), D18.2 (A)
unnamed: D19.1 (K), D20.2 (A)
unnamed: D21.2 (A), D22.1 (K)
unnamed: F1.1, FL1.2
unnamed: F1.2, P2.1
unnamed: F2.1, FL1.1
unnamed: F2.2, P1.1
unnamed: FL1.3, R33.1
unnamed: FL1.4, R37.1
unnamed: R3.1, R4.2
unnamed: R8.1, R12.2, U1.1
unnamed: R5.2, R15.2, U2.1
unnamed: R19.1, R23.2, T2.2 (B), U1.3
unnamed: R24.2, R25.1, T3.2 (B)
unnamed: R27.2, T3.3 (C), U1.4
unnamed: R32.1, R33.2
unnamed: R34.1, R35.2
unnamed: R36.1, R37.2

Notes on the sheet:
- Lethal voltage is present in this circuit (1,160 Volts) - Is highly recommended to GROUND output negative pole with an impedance less than 10 Ω for input voltage up to 300 V.
INPUT VOLTAGE: AC: 100 ~ 820 Volts (45 ~ 450 Hz) DC: 142 ~ 1,160 Volts
1,460 Volts peak
<- Insulated output voltage: 25.8 Volts / 20 Watts
CAUTION HIGH VOLTAGE 142 V to 1,160 V
DIY: High Voltage Range SMPS with Flyback topology for industrial & home application
There are two ground planes Be careful when analyze this circuit

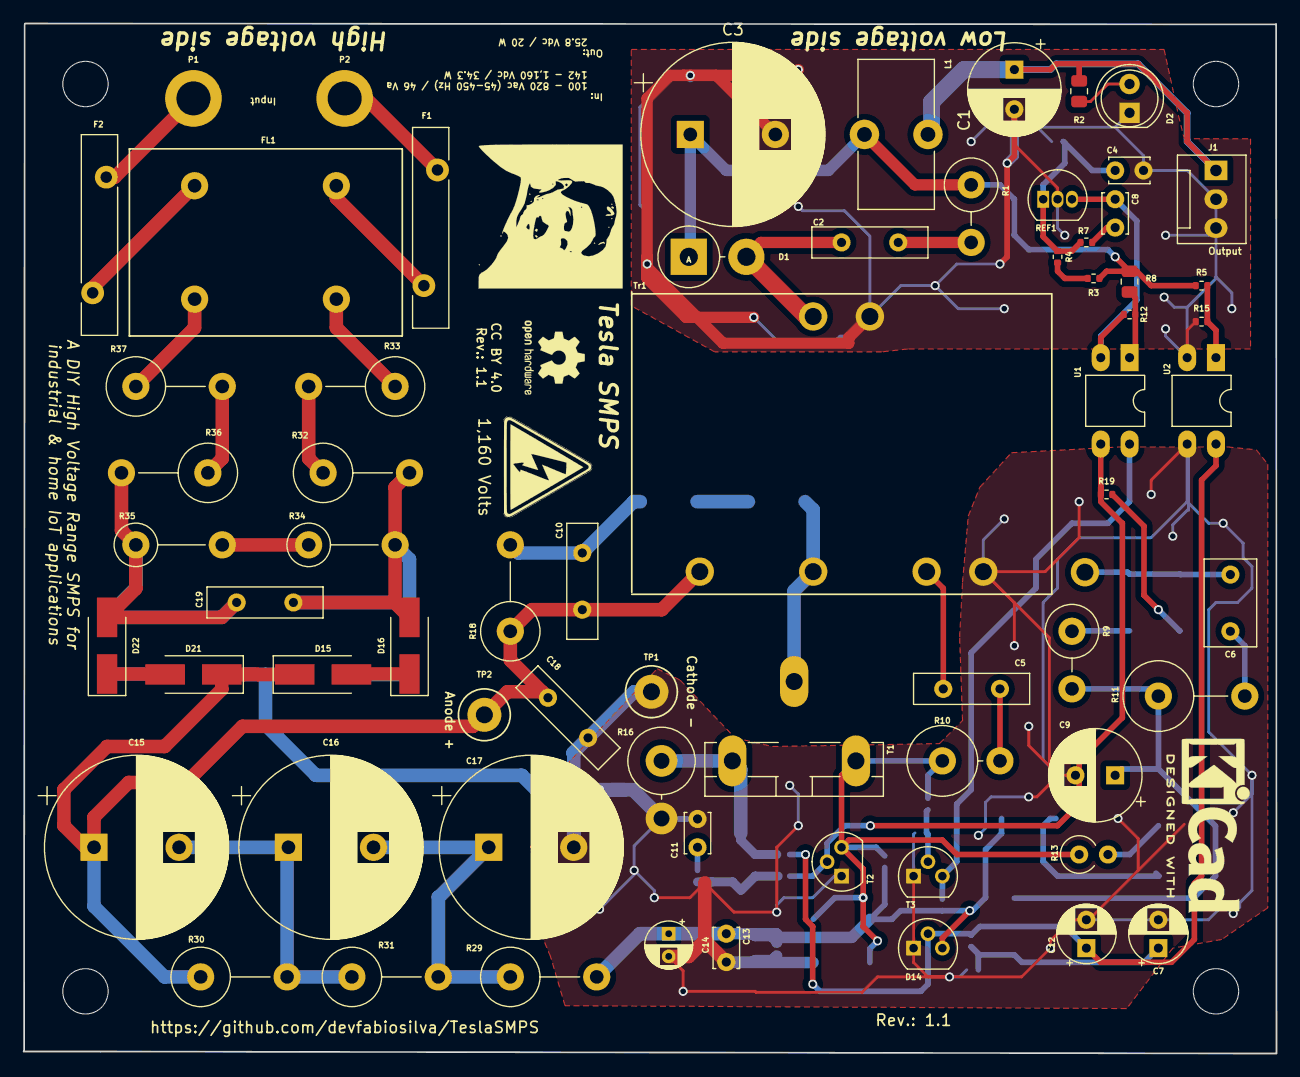
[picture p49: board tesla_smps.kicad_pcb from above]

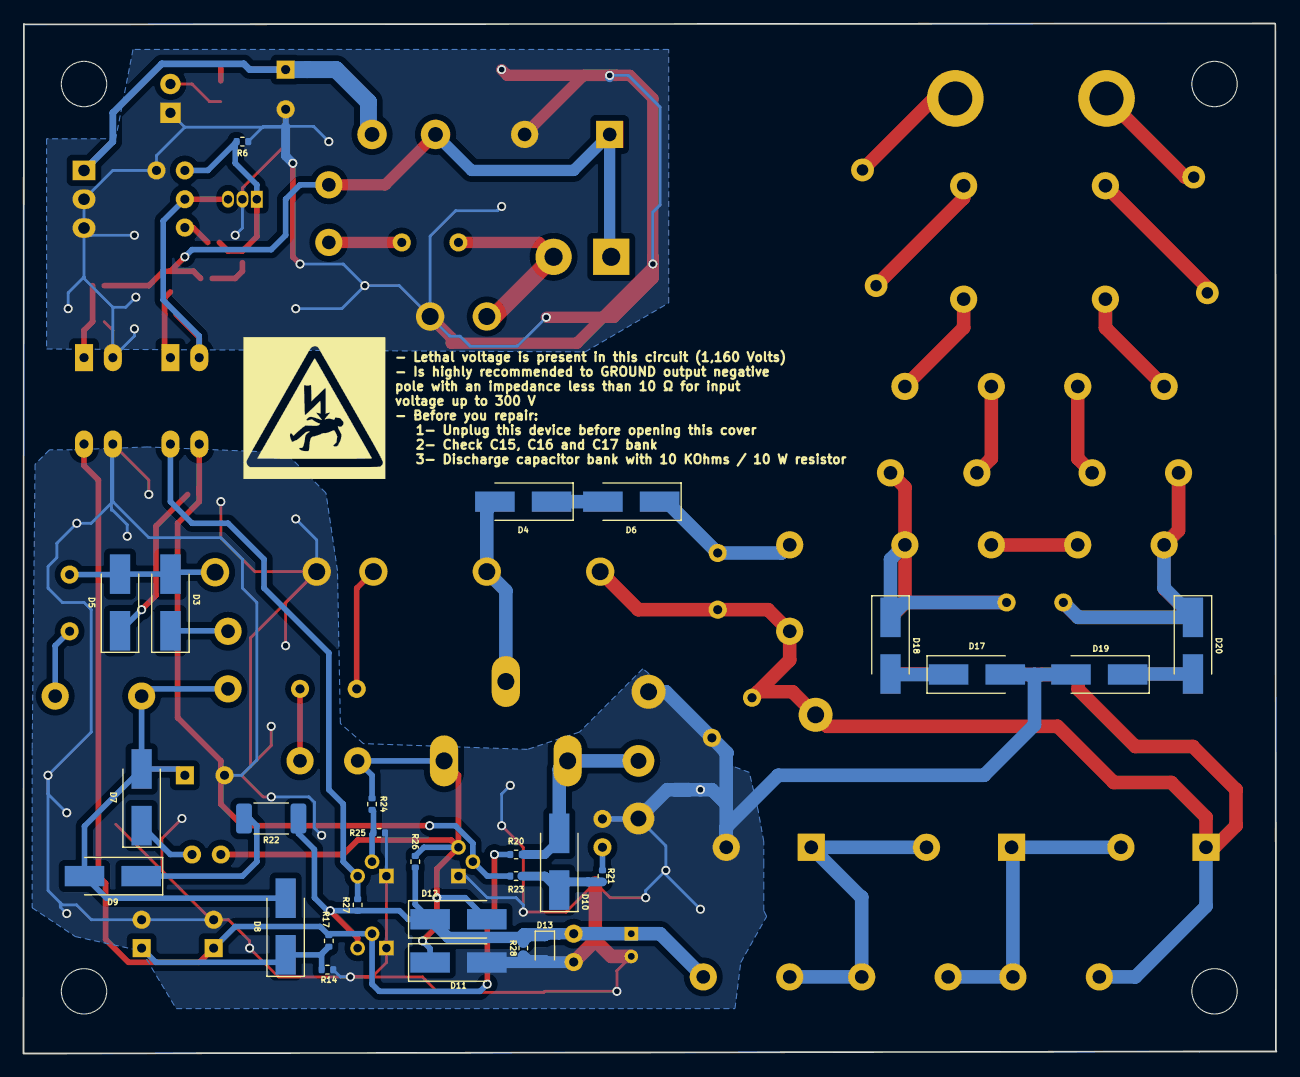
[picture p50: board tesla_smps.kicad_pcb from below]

Board: 2 copper layers, 110.5 x 90.8 mm, 94 parts (27 on the bottom side), 53 nets.

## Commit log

2024-06-30 Working on documentation
    [tesla_smps-Cobre traseira.gbr, tesla_smps-Cortes contorno.gbr, tesla_smps-Mascara frontal.gbr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]
2024-07-14 Update to Kicad 8
    [tesla_smps.kicad_pcb, tesla_smps.kicad_sch]
2024-07-15 Add PCB layout example
2024-08-05 Add new PCB version and changelogs
    [tesla_smps-Cortes contorno.gbr, tesla_smps-Mascara frontal.gbr, tesla_smps-Mascara traseira.gbr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]
2025-03-29 Add release candidate for PCB version 1.1
    [tesla_smps.kicad_pcb, tesla_smps.kicad_sch]
2026-07-01 Update Sponsor PCBWay | KiCad contest

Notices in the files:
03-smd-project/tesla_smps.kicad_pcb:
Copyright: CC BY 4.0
